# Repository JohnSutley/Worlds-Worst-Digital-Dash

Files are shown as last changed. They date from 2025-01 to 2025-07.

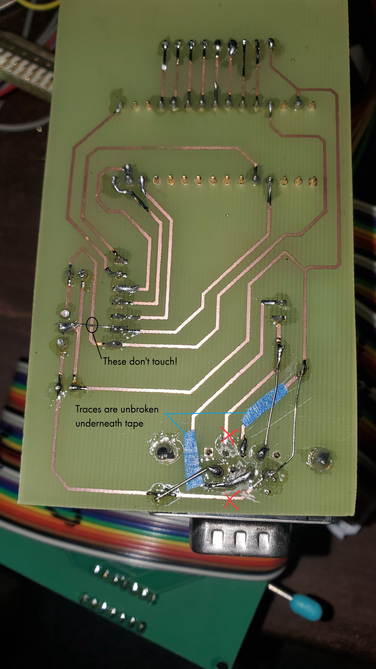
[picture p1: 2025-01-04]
PCBs/Version 1/Arduino attachment/Arduino Canbus Card/Project Note.jpg

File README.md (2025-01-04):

This folder contains the project files for the Worlds Worst Digital Dash
(Gameboy Digital Dash) project. If attempting to recreate version 1 of the
Arduino CANBUS card, please make a note of the included "Project Note" and 
"Project Note 2" pictures in the "Arduino Canbus Card" project folder, since 
I totally messed up the DB9 connector pinout and missed a trace leading to 
the 7805 voltage regulator. Also, I had to bridge some connections on top of 
the Arduino. Gotta admit, not my best work. The "reader.gb" file in the 
Gameboy Code folder is the pre-compiled binary that gets flashed to the EEPROM. 
The software used in this project is as follows:

-Kicad 7.0

-Autodesk Fusion 2.0.20494 x86_64

-Arduino IDE Version: 2.3.4

-GBDK-2020

-Savvy CAN V208

-Xgpro v12.66

-UltiMaker Cura 5.6.0

-LightBurn 1.6.03

-GIMP 2.10.36

-Visual Studio Code Version: 1.96.2

I think LightBurn was the only paid software I used, and that was for the
laser engraver.

Feel free to contact me with any questions regarding this project at
jcsutley@gmail.com. 

John Sutley - 2025

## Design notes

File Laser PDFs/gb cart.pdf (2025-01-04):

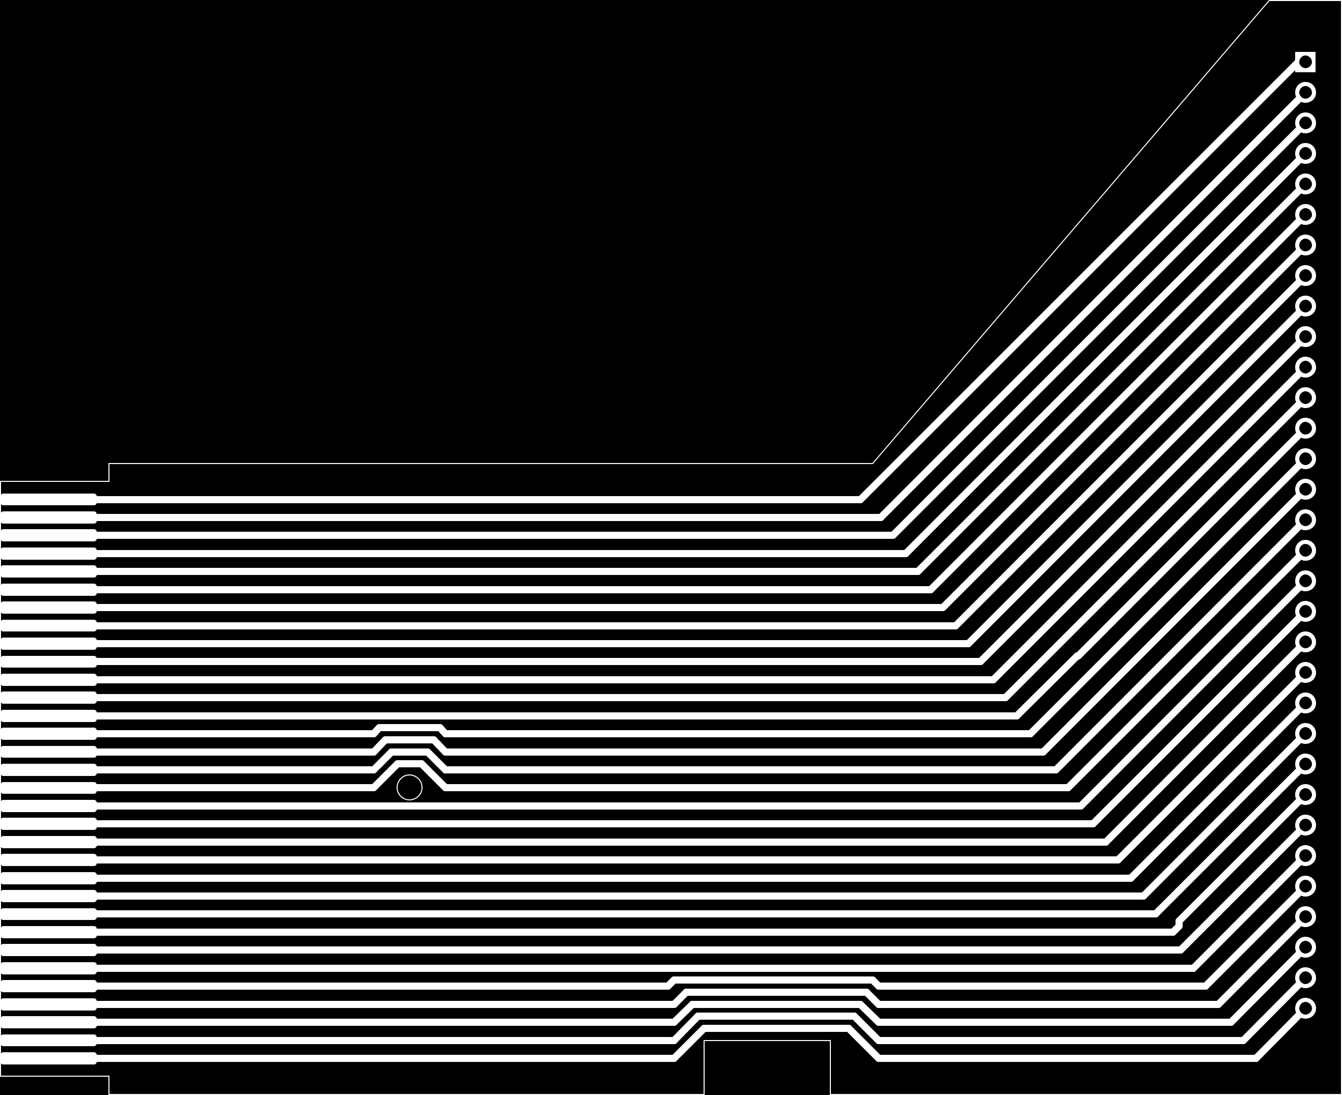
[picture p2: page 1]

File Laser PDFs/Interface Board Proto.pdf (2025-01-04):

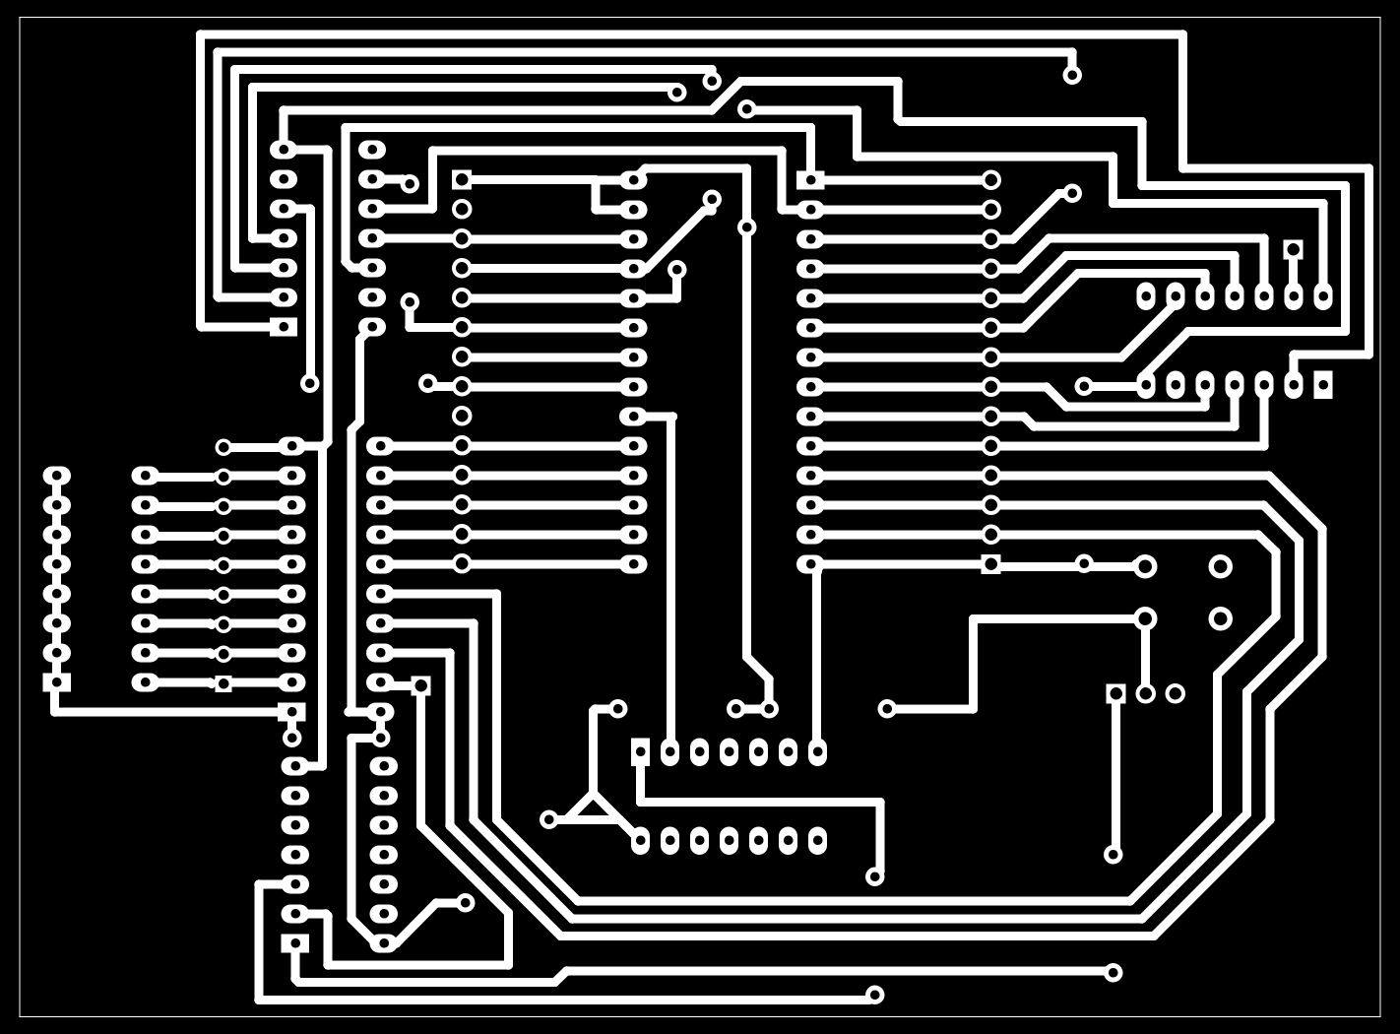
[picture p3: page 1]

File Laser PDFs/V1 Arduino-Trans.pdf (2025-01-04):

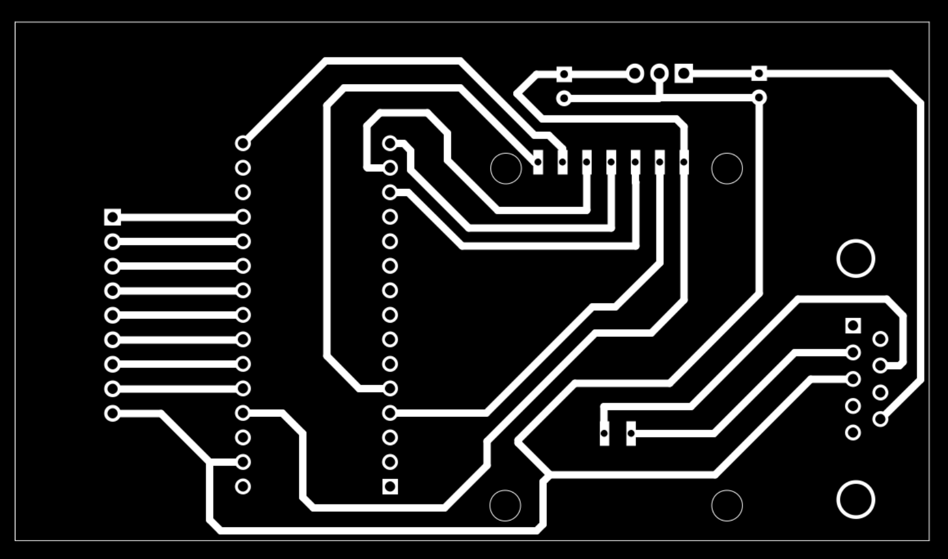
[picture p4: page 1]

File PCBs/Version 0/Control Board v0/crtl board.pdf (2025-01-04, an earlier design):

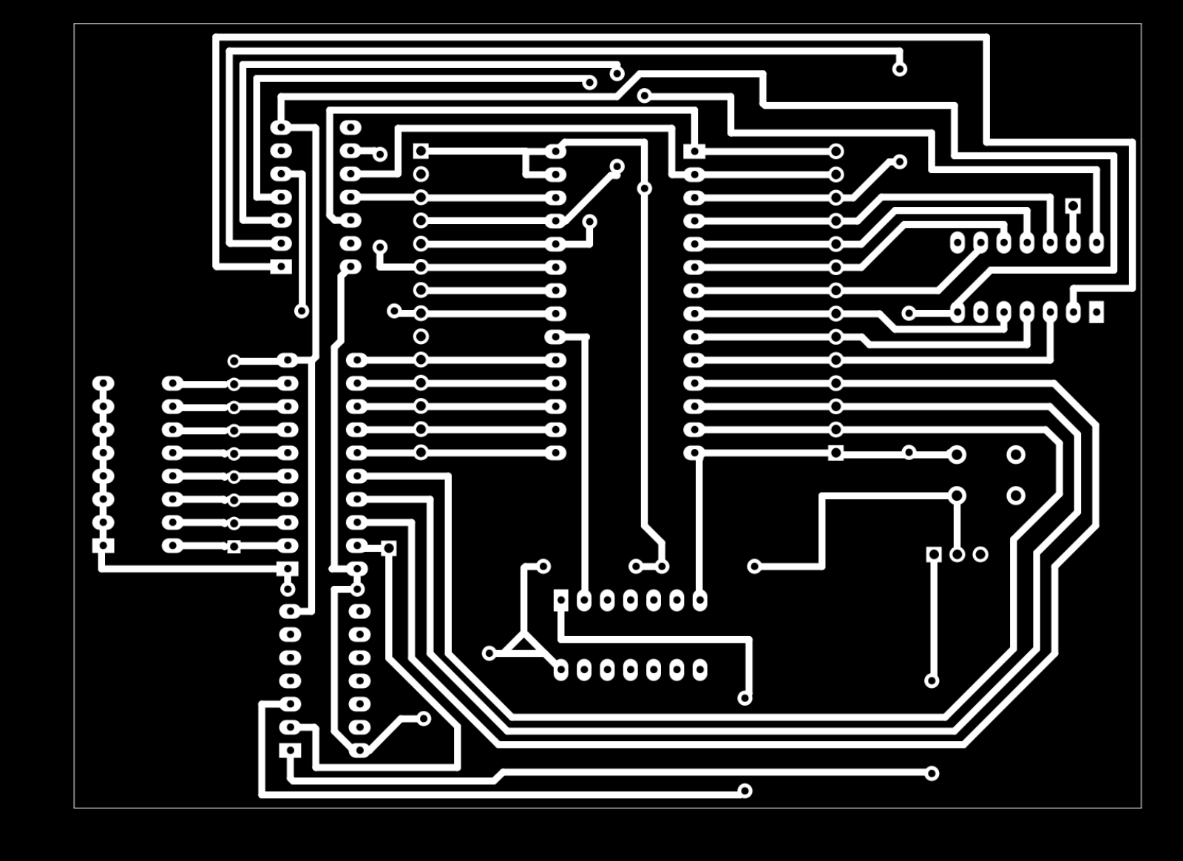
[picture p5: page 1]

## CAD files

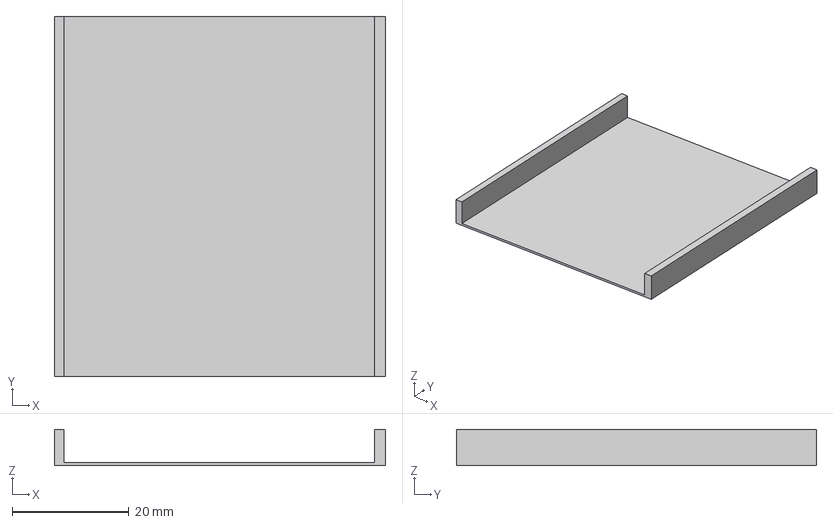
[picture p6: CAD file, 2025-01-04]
GB PAK Adapter/game boy pak shell v3.3mf
56.8 x 61.7 x 6.20 mm

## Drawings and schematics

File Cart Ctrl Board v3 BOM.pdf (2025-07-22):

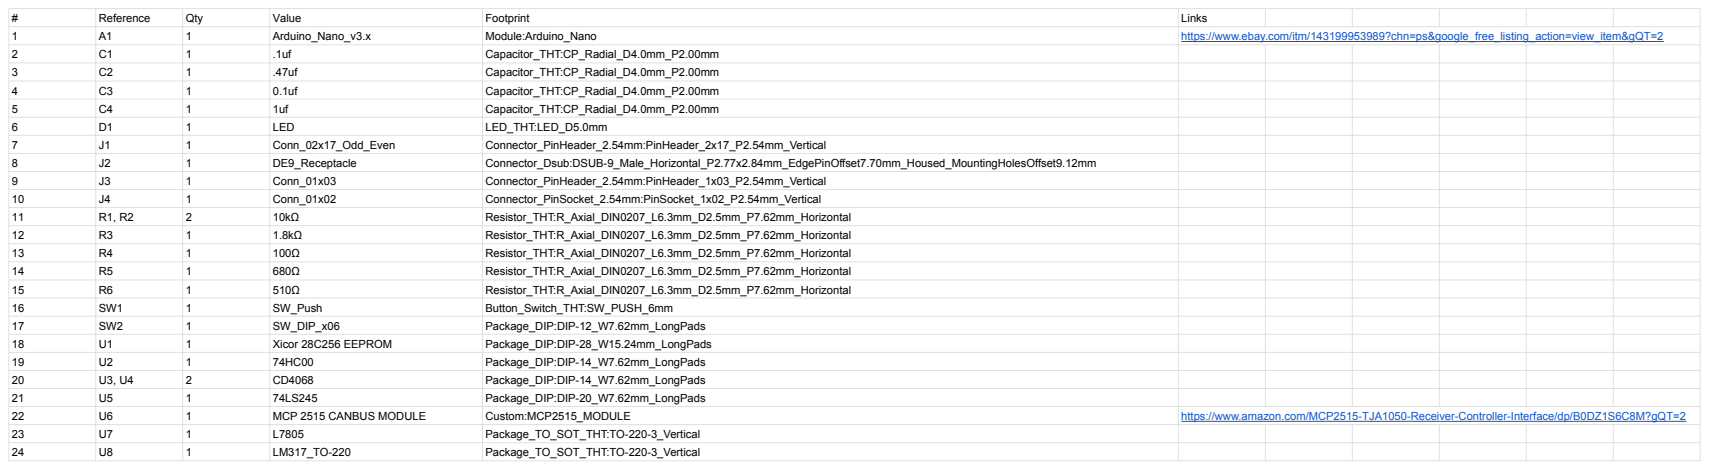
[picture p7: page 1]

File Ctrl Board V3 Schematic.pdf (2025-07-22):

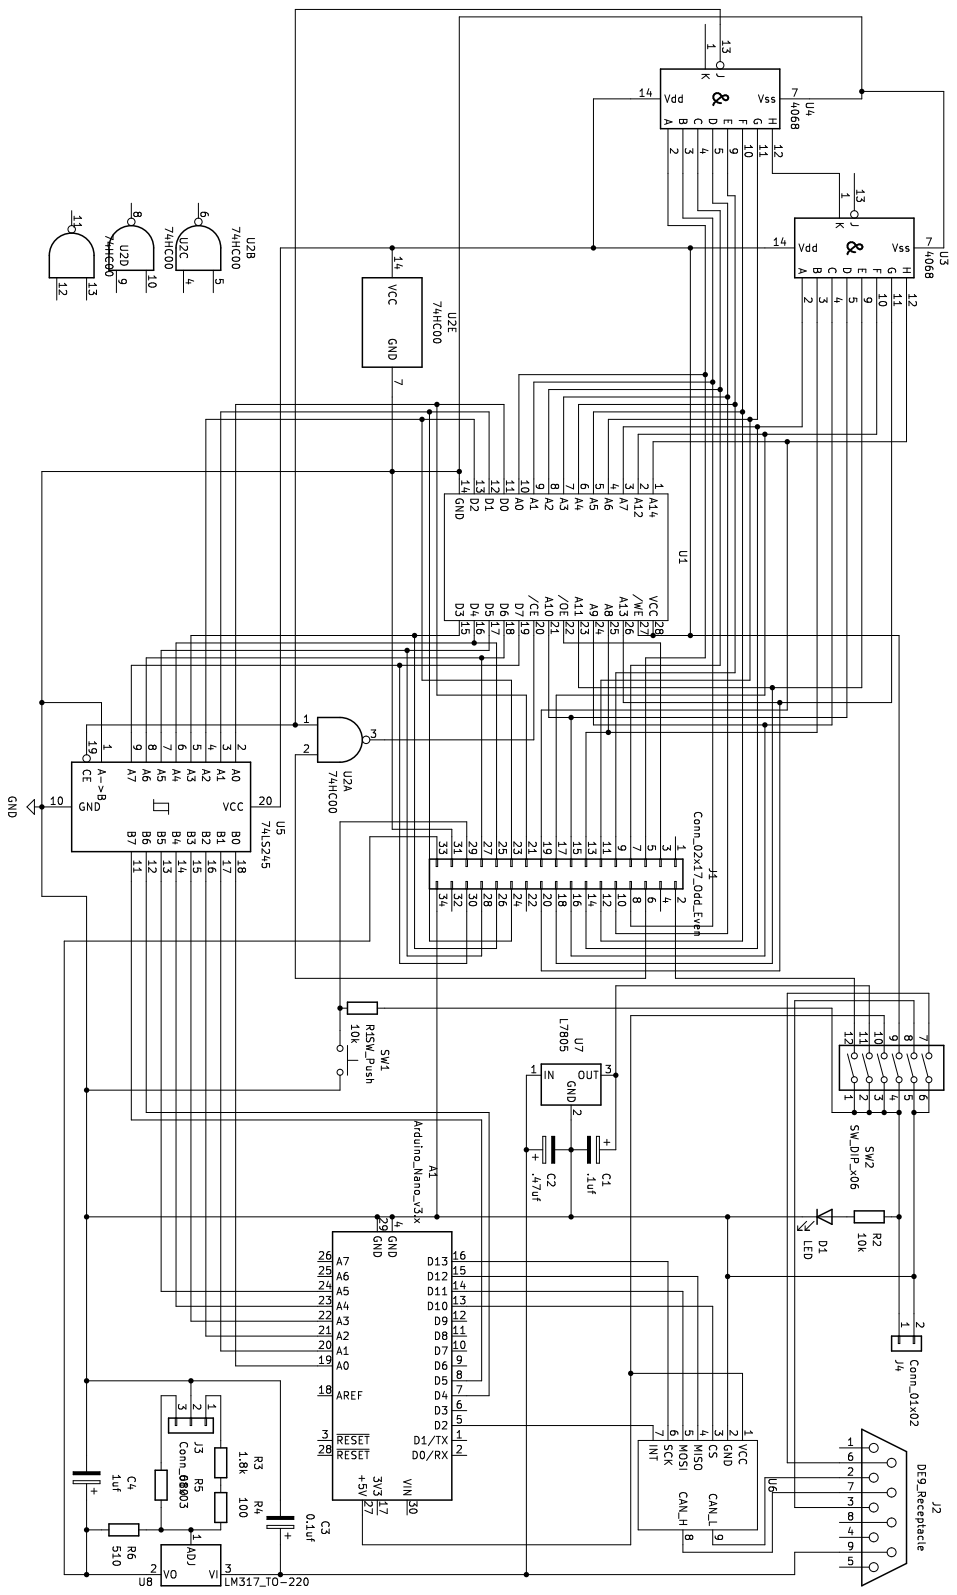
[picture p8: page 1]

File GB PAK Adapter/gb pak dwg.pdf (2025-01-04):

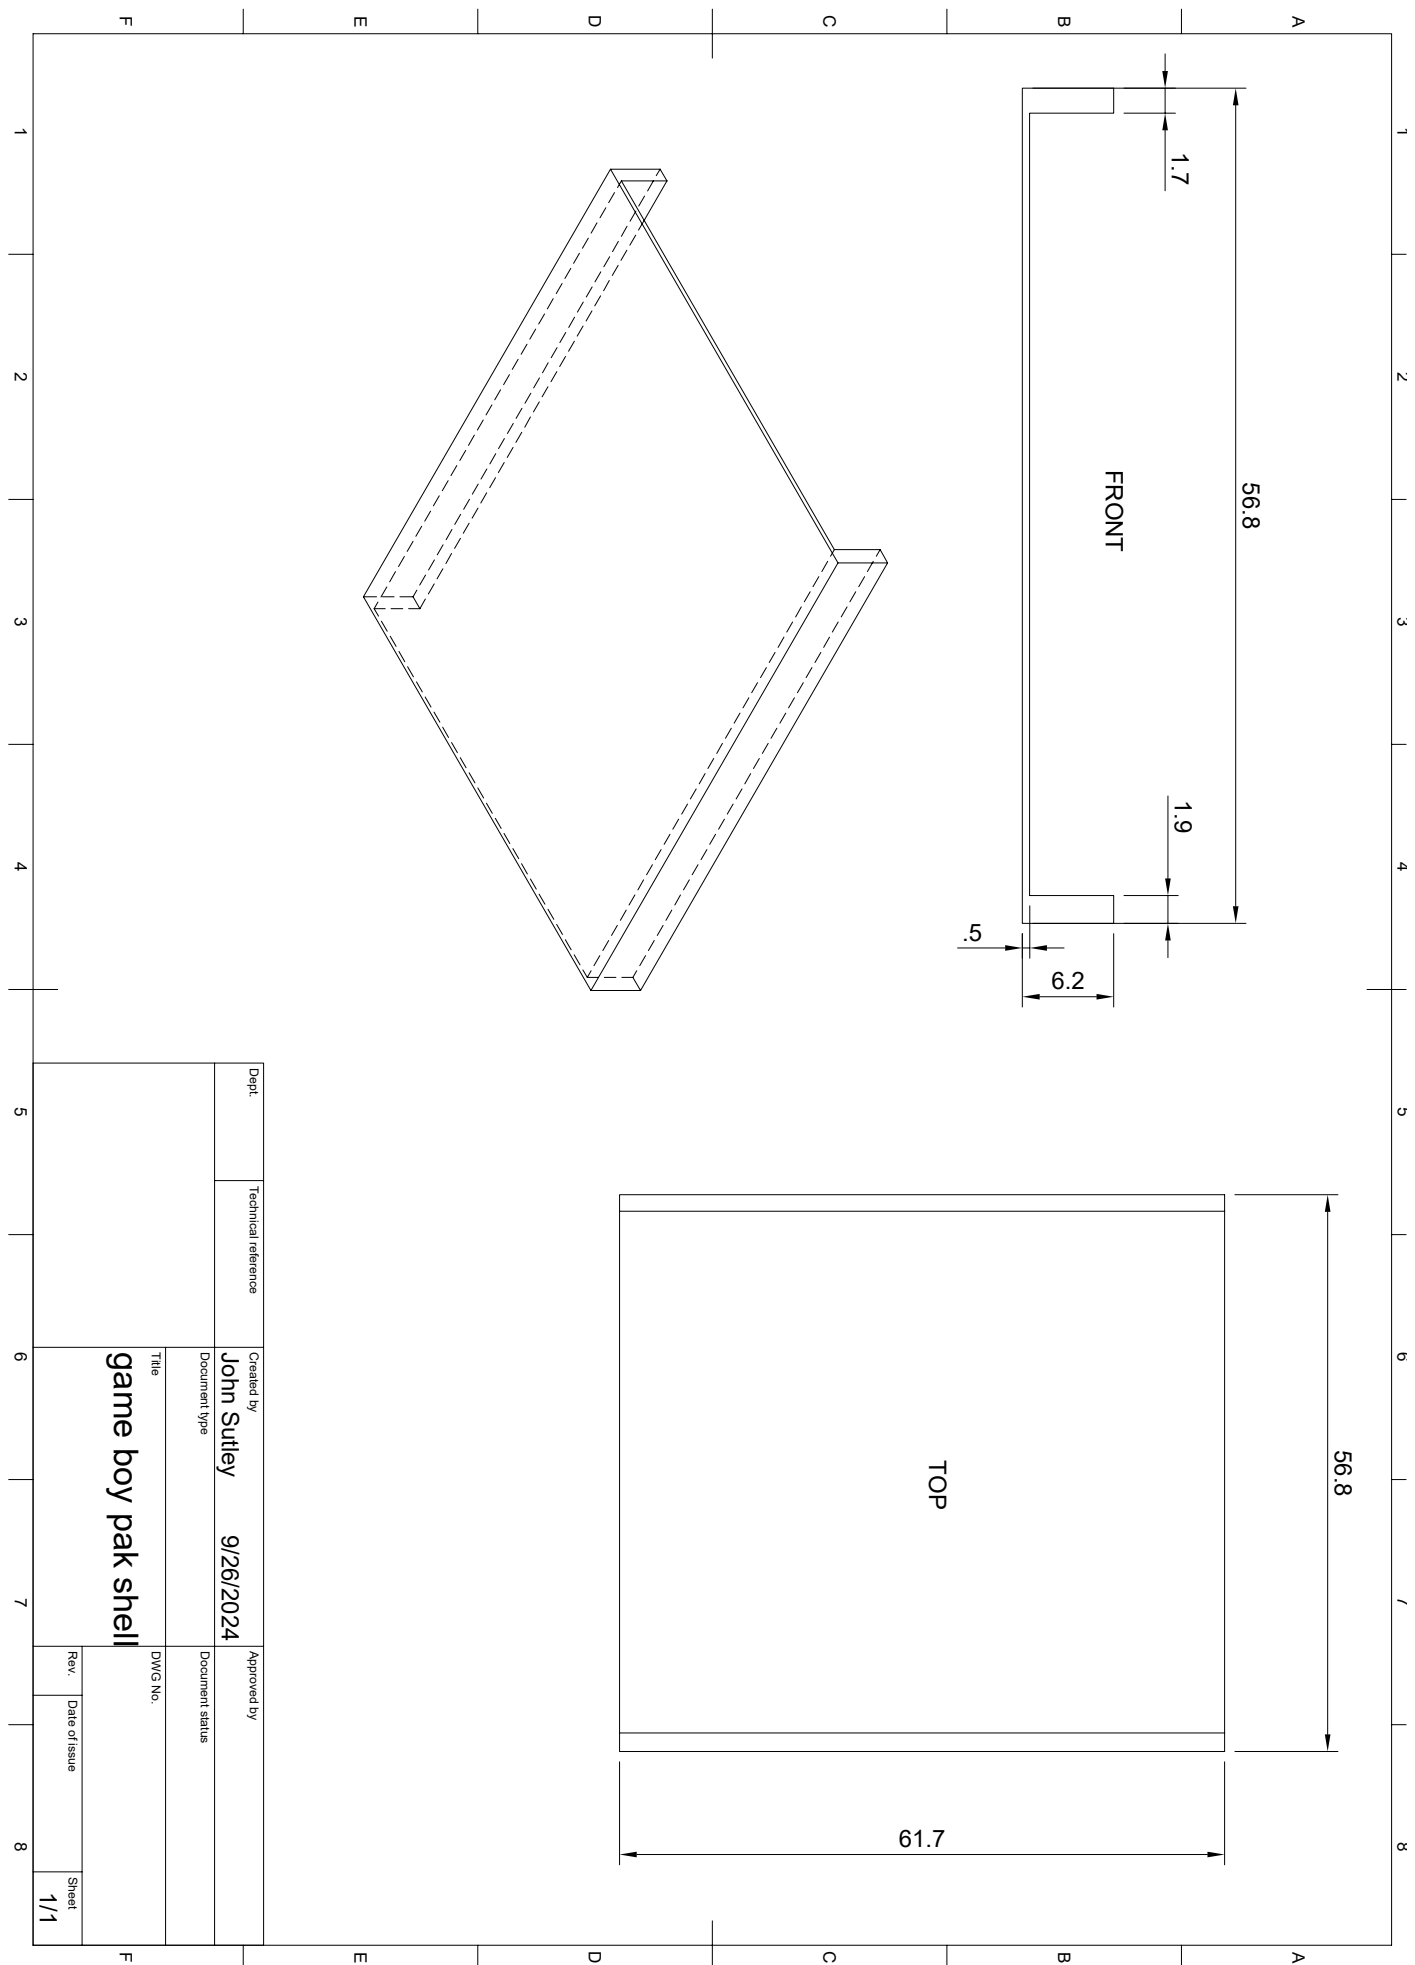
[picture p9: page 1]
61.7 FRONT TOP

1 A 2 3 4 5 6 7 8 1 2 3 4 5 6 7 8 FEDCB FEDCBA Dept. Technical reference Created by Approved by Title DWG No. Document type Document status Rev. Date of issue Sheet 9/26/2024 1/1 game boy pak shell John Sutley 1.7 1.9 56.8

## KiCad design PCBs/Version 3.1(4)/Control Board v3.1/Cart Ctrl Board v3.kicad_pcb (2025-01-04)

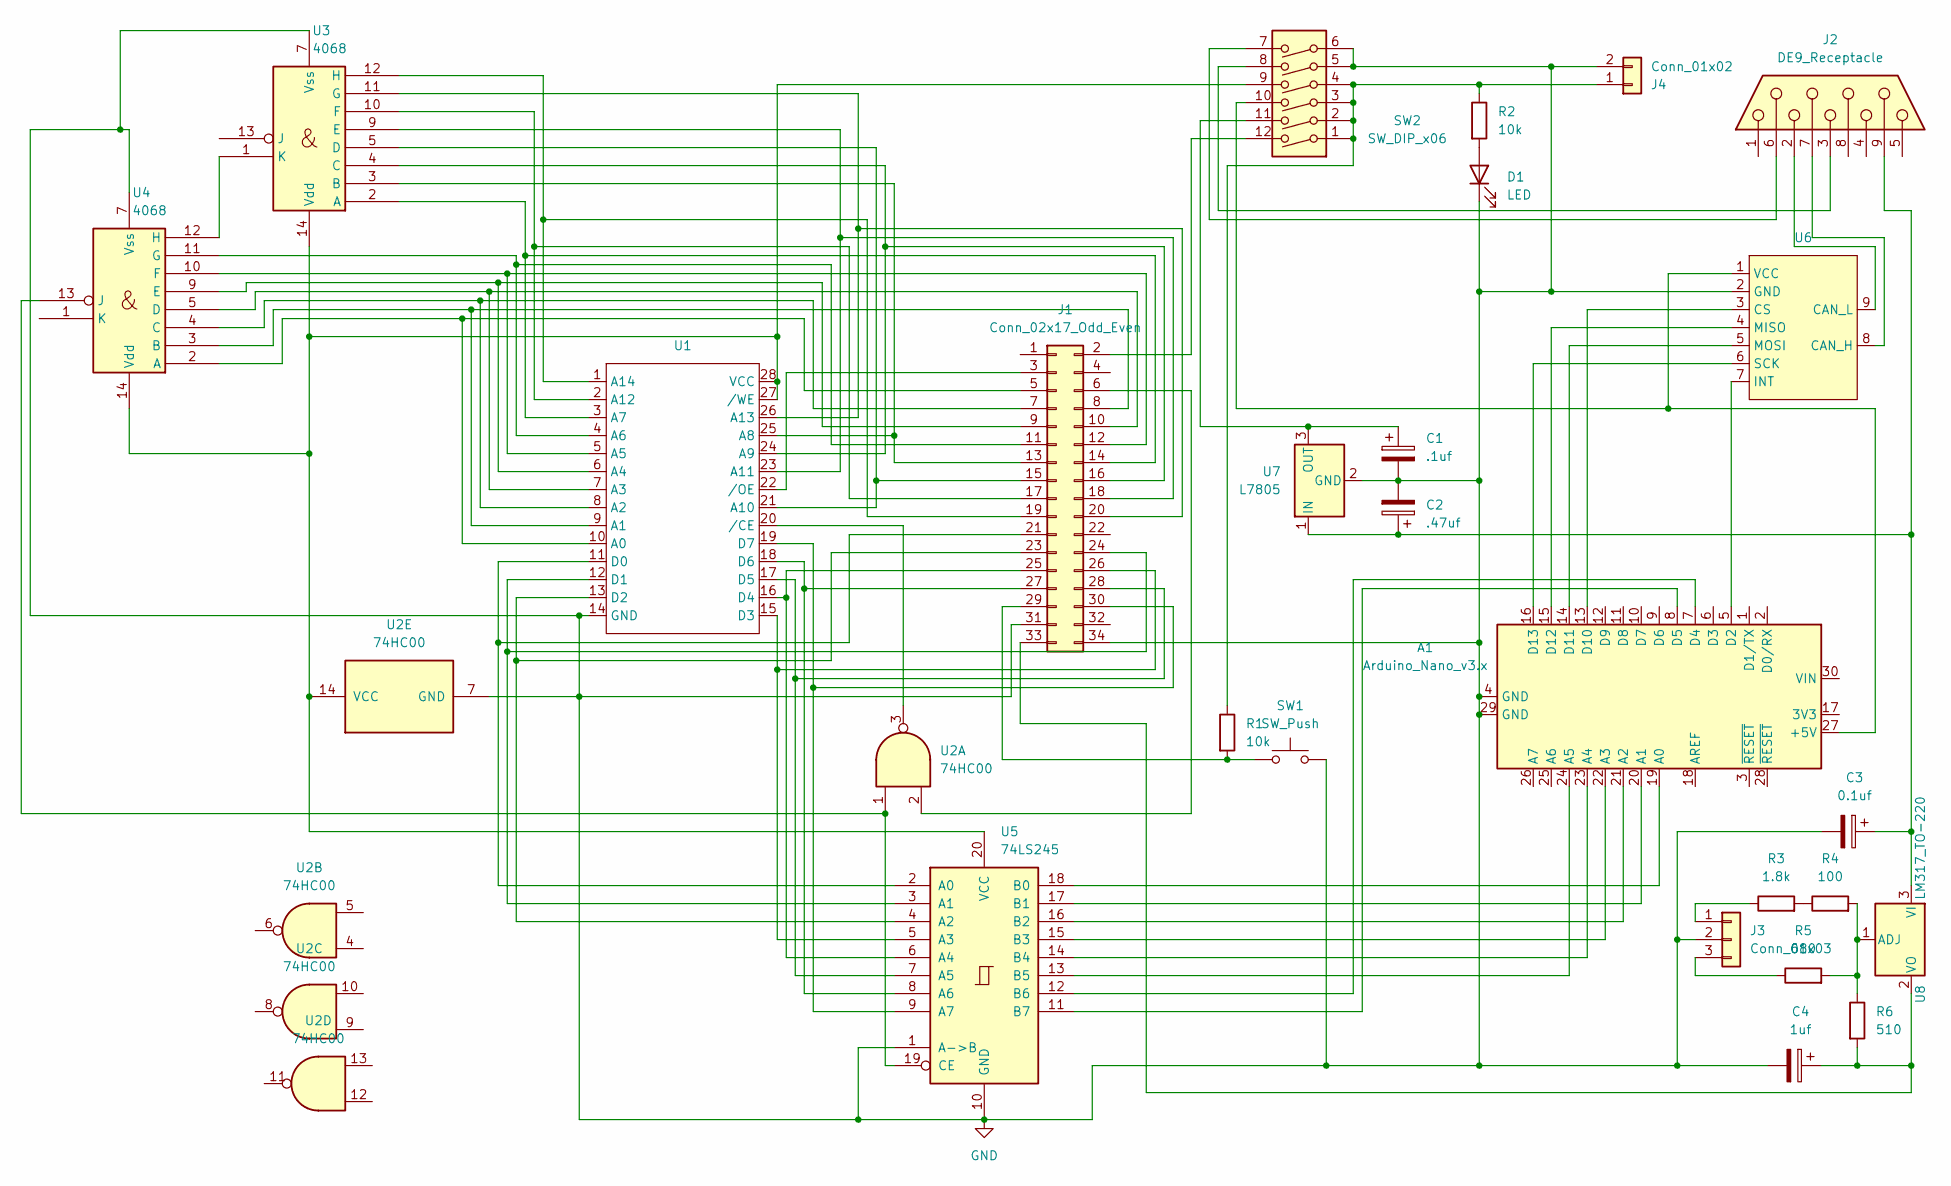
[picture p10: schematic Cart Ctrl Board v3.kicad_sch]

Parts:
A1: Arduino_Nano_v3.x; Arduino_Nano
C1: .1uf; CP_Radial_D4.0mm_P2.00mm
C2: .47uf; CP_Radial_D4.0mm_P2.00mm
C3: 0.1uf; CP_Radial_D4.0mm_P2.00mm
C4: 1uf; CP_Radial_D4.0mm_P2.00mm
D1: LED; LED_D5.0mm
J1: Conn_02x17_Odd_Even; PinHeader_2x17_P2.54mm_Vertical
J2: DE9_Receptacle; DSUB-9_Male_Horizontal_P2.77x2.84mm_EdgePinOffset7.70mm_Hou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
J3: Conn_01x03; PinHeader_1x03_P2.54mm_Vertical
J4: Conn_01x02; PinSocket_1x02_P2.54mm_Vertical
R1, R2: 10k; R_Axial_DIN0207_L6.3mm_D2.5mm_P7.62mm_Horizontal
R3: 1.8k; R_Axial_DIN0207_L6.3mm_D2.5mm_P7.62mm_Horizontal
R4: 100; R_Axial_DIN0207_L6.3mm_D2.5mm_P7.62mm_Horizontal
R5: 680; R_Axial_DIN0207_L6.3mm_D2.5mm_P7.62mm_Horizontal
R6: 510; R_Axial_DIN0207_L6.3mm_D2.5mm_P7.62mm_Horizontal
SW1: SW_Push; SW_PUSH_6mm
SW2: SW_DIP_x06; DIP-12_W7.62mm_LongPads
U1: DIP-28_W15.24mm_LongPads
U2: 74HC00; DIP-14_W7.62mm_LongPads
U3, U4: 4068; DIP-14_W7.62mm_LongPads
U5: 74LS245; DIP-20_W7.62mm_LongPads
U6: MCP2515_MODULE
U7: L7805; TO-220-3_Vertical
U8: LM317_TO-220; TO-220-3_Vertical

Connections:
GND: A1.4 (GND), A1.29 (GND), C1.2, C2.2, C3.2, C4.2, D1.1 (K), J1.31, J1.34, J3.2, J4.2, SW1.2, SW2.5, SW2.6, U1.14 (GND), U2.7 (GND), U3.7 (Vss), U4.7 (Vss), U5.1 (A->B), U5.10 (GND), U6.2 (GND), U7.2 (GND)
unnamed: A1.27 (+5V), SW2.10, U6.1 (VCC)
unnamed: A1.19 (A0), U5.18 (B0)
unnamed: A1.20 (A1), U5.17 (B1)
unnamed: A1.21 (A2), U5.16 (B2)
unnamed: A1.22 (A3), U5.15 (B3)
unnamed: A1.23 (A4), U5.14 (B4)
unnamed: A1.24 (A5), U5.13 (B5)
unnamed: A1.5 (D2), U6.7 (INT)
unnamed: A1.7 (D4), U5.12 (B6)
unnamed: A1.8 (D5), U5.11 (B7)
unnamed: A1.13 (D10), U6.3 (CS)
unnamed: A1.14 (D11), U6.5 (MOSI)
unnamed: A1.15 (D12), U6.4 (MISO)
unnamed: A1.16 (D13), U6.6 (SCK)
unnamed: D1.2 (A), R2.2
unnamed: J1.2, SW2.12
unnamed: J1.3, U1.22 (/OE)
unnamed: J1.5, U1.10 (A0), U4.2 (A)
unnamed: J1.6, U2.2
unnamed: J1.7, U1.8 (A2), U4.4 (C)
unnamed: J1.8, U1.9 (A1), U4.3 (B)
unnamed: J1.9, U1.6 (A4), U4.9 (E)
unnamed: J1.10, U1.7 (A3), U4.5 (D)
unnamed: J1.11, U1.4 (A6), U4.11 (G)
unnamed: J1.12, U1.5 (A5), U4.10 (F)
unnamed: J1.13, U1.25 (A8), U3.3 (B)
unnamed: J1.14, U1.3 (A7), U3.2 (A)
unnamed: J1.15, U1.21 (A10), U3.5 (D)
unnamed: J1.16, U1.24 (A9), U3.4 (C)
unnamed: J1.17, U1.2 (A12), U3.10 (F)
unnamed: J1.18, U1.23 (A11), U3.9 (E)
unnamed: J1.19, U1.1 (A14), U3.12 (H)
unnamed: J1.20, U1.26 (A13), U3.11 (G)
unnamed: J1.21, U1.11 (D0), U5.2 (A0)
unnamed: J1.23, U1.13 (D2), U5.4 (A2)
unnamed: J1.24, U1.12 (D1), U5.3 (A1)
unnamed: J1.25, U1.16 (D4), U5.6 (A4)
unnamed: J1.26, U1.15 (D3), U5.5 (A3)
unnamed: J1.27, U1.18 (D6), U5.8 (A6)
unnamed: J1.28, U1.17 (D5), U5.7 (A5)
unnamed: J1.29, R1.2, SW1.1
unnamed: J1.30, U1.19 (D7), U5.9 (A7)
unnamed: C4.1, J1.33, R6.2, U8.2 (VO)
unnamed: J2.3, SW2.8
unnamed: J2.6, SW2.7
unnamed: J3.1, R3.1
unnamed: J3.3, R5.1
unnamed: J4.1, R1.1, R2.1, SW2.1, SW2.2, SW2.3, SW2.4
unnamed: R3.2, R4.1
unnamed: SW2.9, U1.27 (/WE), U1.28 (VCC), U2.14 (VCC), U3.14 (Vdd), U4.14 (Vdd), U5.20 (VCC)
unnamed: U1.20 (/CE), U2.3
unnamed: U3.1 (K), U4.12 (H)
unnamed: U2.1, U4.13 (J), U5.19 (CE)
unnamed: J2.7, U6.8 (CAN_H)
unnamed: J2.2, U6.9 (CAN_L)
unnamed: C2.1, C3.1, J2.9, U7.1 (IN), U8.3 (VI)
unnamed: C1.1, SW2.11, U7.3 (OUT)
unnamed: R4.2, R5.2, R6.1, U8.1 (ADJ)

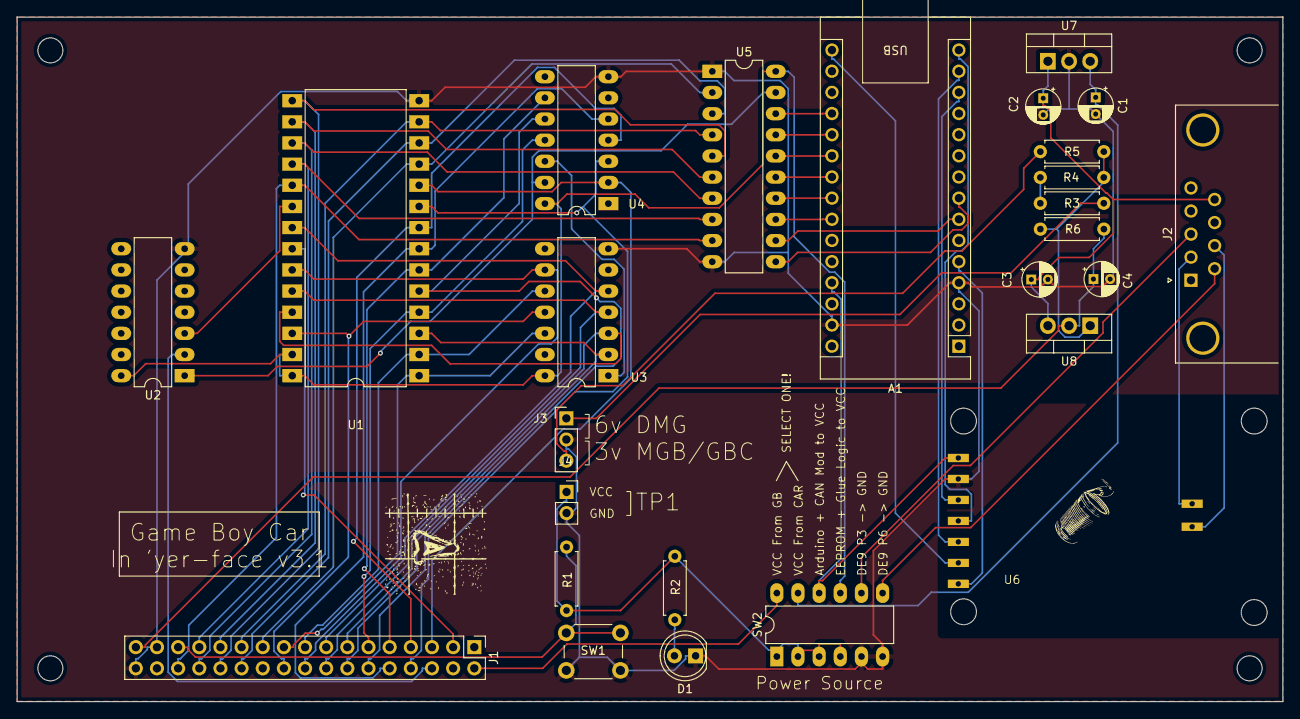
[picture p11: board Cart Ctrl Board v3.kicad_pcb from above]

Board: 2 copper layers, 152.0 x 82.2 mm, 26 parts (0 on the bottom side), 59 nets.

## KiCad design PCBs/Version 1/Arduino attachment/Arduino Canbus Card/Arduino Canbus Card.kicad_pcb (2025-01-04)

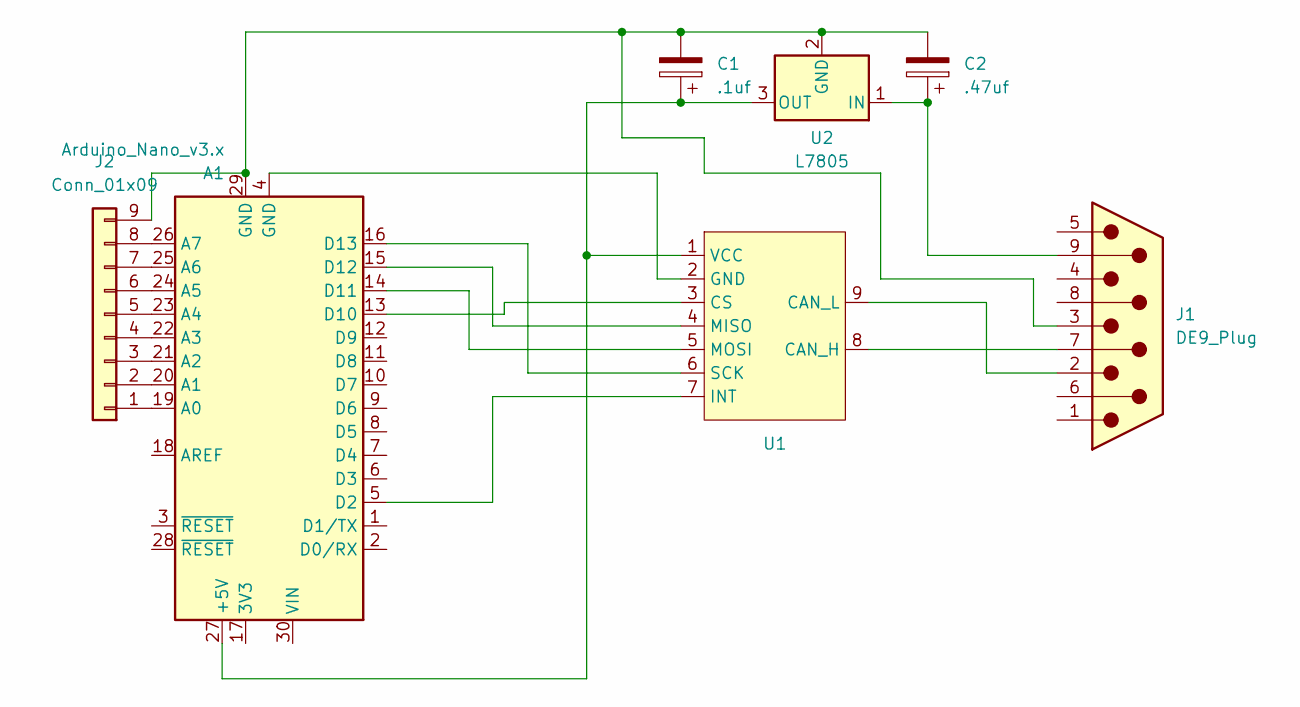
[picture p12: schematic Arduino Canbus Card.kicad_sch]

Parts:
A1: Arduino_Nano_v3.x; Arduino_Nano
C1: .1uf; CP_Radial_D5.0mm_P2.50mm
C2: .47uf; CP_Radial_D5.0mm_P2.50mm
J1: DE9_Plug; DSUB-9_Female_Horizontal_P2.77x2.84mm_EdgePinOffset4.94mm_H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
J2: Conn_01x09; PinSocket_1x09_P2.54mm_Horizontal
U1: MCP2515_MODULE
U2: L7805; TO-220-3_Vertical

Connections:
unnamed: A1.27 (+5V), C1.1, U1.1 (VCC), U2.3 (OUT)
unnamed: A1.19 (A0), J2.1
unnamed: A1.20 (A1), J2.2
unnamed: A1.21 (A2), J2.3
unnamed: A1.22 (A3), J2.4
unnamed: A1.23 (A4), J2.5
unnamed: A1.24 (A5), J2.6
unnamed: A1.25 (A6), J2.7
unnamed: A1.26 (A7), J2.8
unnamed: A1.5 (D2), U1.7 (INT)
unnamed: A1.13 (D10), U1.3 (CS)
unnamed: A1.14 (D11), U1.5 (MOSI)
unnamed: A1.15 (D12), U1.4 (MISO)
unnamed: A1.16 (D13), U1.6 (SCK)
unnamed: A1.29 (GND), C1.2, C2.2, J1.3, J2.9, U2.2 (GND)
unnamed: J1.7, U1.8 (CAN_H)
unnamed: J1.2, U1.9 (CAN_L)
unnamed: A1.4 (GND), U1.2 (GND)
unnamed: C2.1, J1.9, U2.1 (IN)

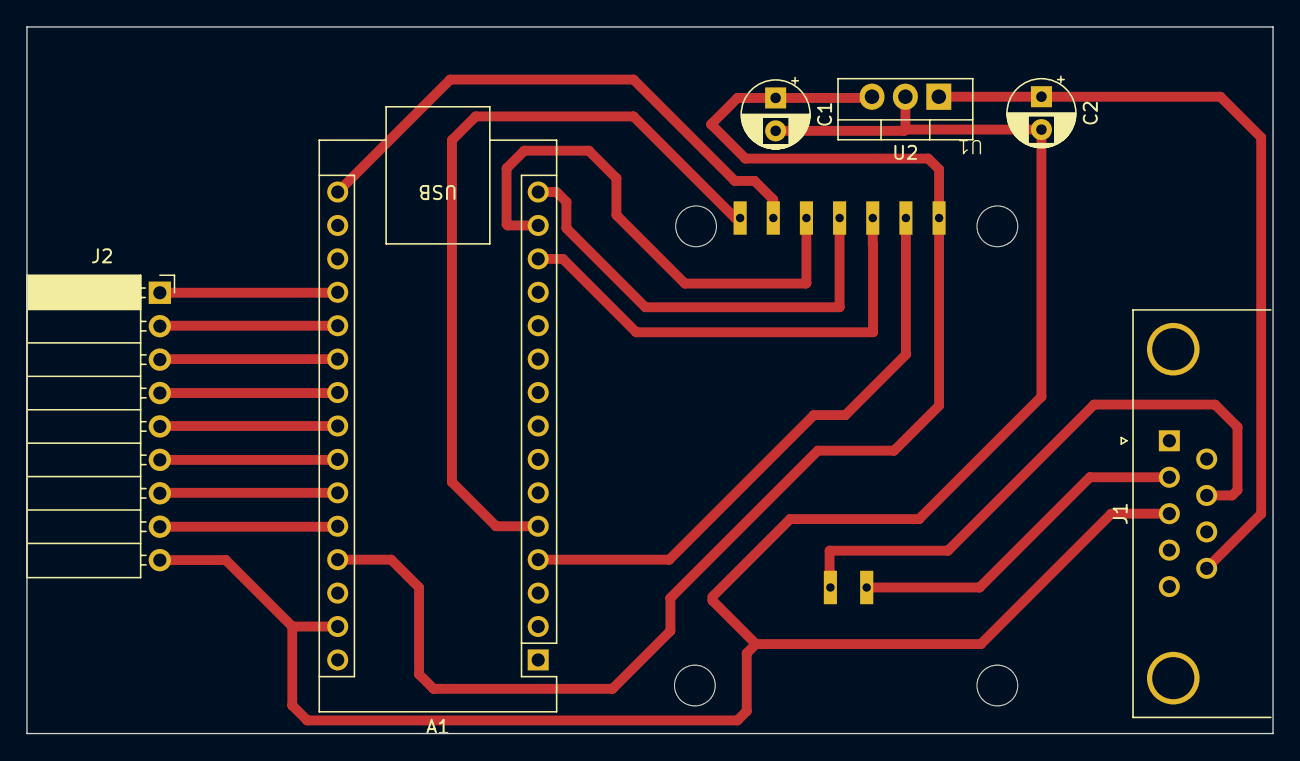
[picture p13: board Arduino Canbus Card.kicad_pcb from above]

Board: 2 copper layers, 94.7 x 53.7 mm, 7 parts (0 on the bottom side), 19 nets.

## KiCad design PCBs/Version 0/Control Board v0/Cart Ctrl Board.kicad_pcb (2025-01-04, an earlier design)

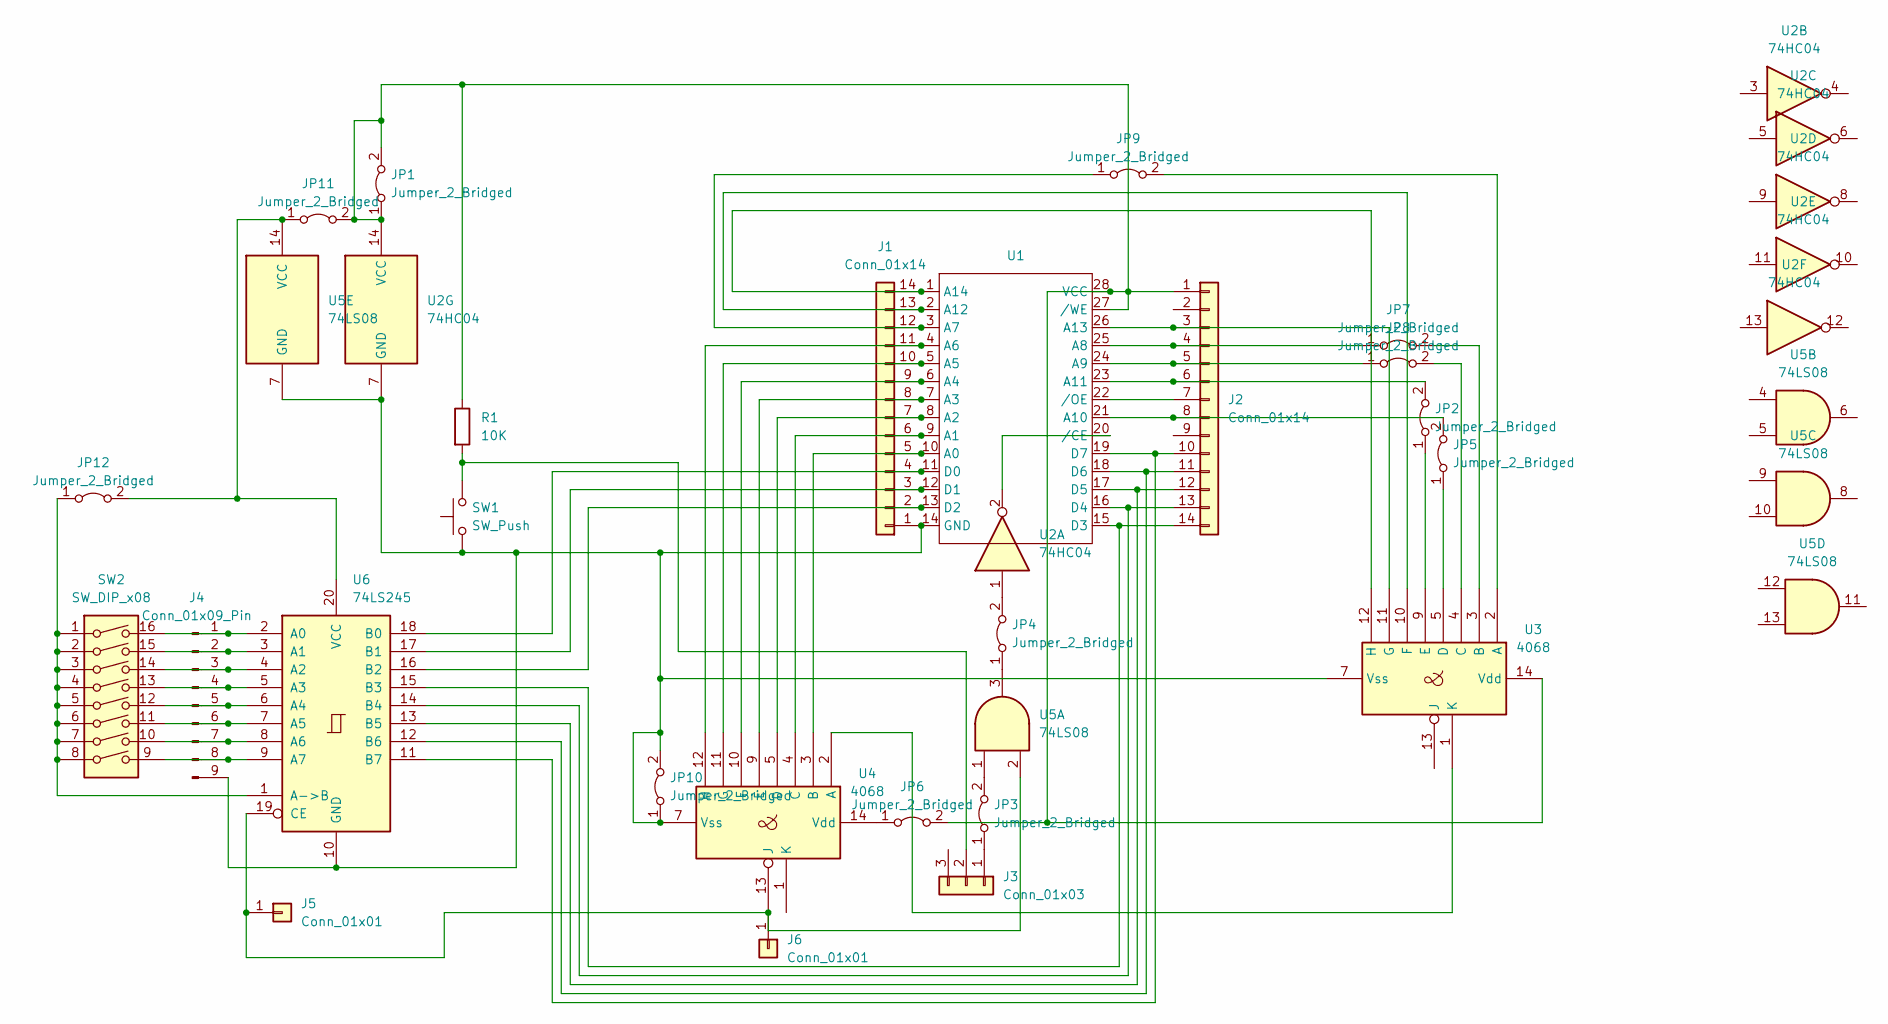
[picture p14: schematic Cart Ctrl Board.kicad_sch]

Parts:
J1, J2: Conn_01x14; PinHeader_1x14_P2.54mm_Vertical
J3: Conn_01x03; PinHeader_1x03_P2.54mm_Vertical
J4: Conn_01x09_Pin; SIP-9_22.3x3mm_P2.54mm
J5, J6: Conn_01x01; PinHeader_1x01_P2.54mm_Vertical
JP1, JP2, JP3, JP4, JP5, JP6, JP7, JP9, JP11: Jumper_2_Bridged; R_Axial_DIN0207_L6.3mm_D2.5mm_P10.16mm_Horizontal
JP8, JP10: Jumper_2_Bridged; R_Axial_DIN0207_L6.3mm_D2.5mm_P15.24mm_Horizontal
JP12: Jumper_2_Bridged; R_Axial_DIN0207_L6.3mm_D2.5mm_P7.62mm_Horizontal
R1: 10K; R_Axial_DIN0207_L6.3mm_D2.5mm_P10.16mm_Horizontal
SW1: SW_Push; SW_PUSH_6mm_H5mm
SW2: SW_DIP_x08; DIP-16_W7.62mm_LongPads
U1: DIP-28_W15.24mm_LongPads
U2: 74HC04; DIP-14_W7.62mm_LongPads
U3, U4: 4068; DIP-14_W7.62mm_LongPads
U5: 74LS08; DIP-14_W7.62mm_LongPads
U6: 74LS245; DIP-20_W7.62mm_LongPads

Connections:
unnamed: J1.1, J4.9, JP10.1 (A), JP10.2 (B), SW1.1, U1.14 (GND), U2.7 (GND), U3.7 (Vss), U4.7 (Vss), U5.7 (GND), U6.10 (GND)
unnamed: J1.2, U1.13 (D2), U6.16 (B2)
unnamed: J1.3, U1.12 (D1), U6.17 (B1)
unnamed: J1.4, U1.11 (D0), U6.18 (B0)
unnamed: J1.5, U1.10 (A0), U4.3 (B)
unnamed: J1.6, U1.9 (A1), U4.4 (C)
unnamed: J1.7, U1.8 (A2), U4.5 (D)
unnamed: J1.8, U1.7 (A3), U4.9 (E)
unnamed: J1.9, U1.6 (A4), U4.10 (F)
unnamed: J1.10, U1.5 (A5), U4.11 (G)
unnamed: J1.11, U1.4 (A6), U4.12 (H)
unnamed: J1.12, JP9.1 (A), U1.3 (A7)
unnamed: J1.13, U1.2 (A12), U3.10 (F)
unnamed: J1.14, U1.1 (A14), U3.12 (H)
unnamed: J2.1, JP1.1 (A), JP1.2 (B), JP6.2 (B), JP11.2 (B), R1.1, U1.27 (/WE), U1.28 (VCC), U2.14 (VCC), U3.14 (Vdd)
unnamed: J2.3, U1.26 (A13), U3.11 (G)
unnamed: J2.4, JP7.1 (A), U1.25 (A8)
unnamed: J2.5, JP8.1 (A), U1.24 (A9)
unnamed: J2.6, JP2.2 (B), U1.23 (A11)
unnamed: J2.7, U1.22 (/OE)
unnamed: J2.8, JP5.2 (B), U1.21 (A10)
unnamed: J2.10, U1.19 (D7), U6.11 (B7)
unnamed: J2.11, U1.18 (D6), U6.12 (B6)
unnamed: J2.12, U1.17 (D5), U6.13 (B5)
unnamed: J2.13, U1.16 (D4), U6.14 (B4)
unnamed: J2.14, U1.15 (D3), U6.15 (B3)
unnamed: J3.1, JP3.1 (A)
unnamed: J3.2, R1.2, SW1.2
unnamed: J4.1, SW2.16, U6.2 (A0)
unnamed: J4.2, SW2.15, U6.3 (A1)
unnamed: J4.3, SW2.14, U6.4 (A2)
unnamed: J4.4, SW2.13, U6.5 (A3)
unnamed: J4.5, SW2.12, U6.6 (A4)
unnamed: J4.6, SW2.11, U6.7 (A5)
unnamed: J4.7, SW2.10, U6.8 (A6)
unnamed: J4.8, SW2.9, U6.9 (A7)
unnamed: J5.1, J6.1, U4.13 (J), U5.2, U6.19 (CE)
unnamed: JP2.1 (A), U3.9 (E)
unnamed: JP3.2 (B), U5.1
unnamed: JP4.1 (A), U5.3
unnamed: JP4.2 (B), U2.1
unnamed: JP5.1 (A), U3.5 (D)
unnamed: JP6.1 (A), U4.14 (Vdd)
unnamed: JP7.2 (B), U3.3 (B)
unnamed: JP8.2 (B), U3.4 (C)
unnamed: JP9.2 (B), U3.2 (A)
unnamed: JP11.1 (A), JP12.2 (B), U5.14 (VCC), U6.20 (VCC)
unnamed: JP12.1 (A), SW2.1, SW2.2, SW2.3, SW2.4, SW2.5, SW2.6, SW2.7, SW2.8, U6.1 (A->B)
unnamed: U1.20 (/CE), U2.2
unnamed: U3.1 (K), U4.2 (A)

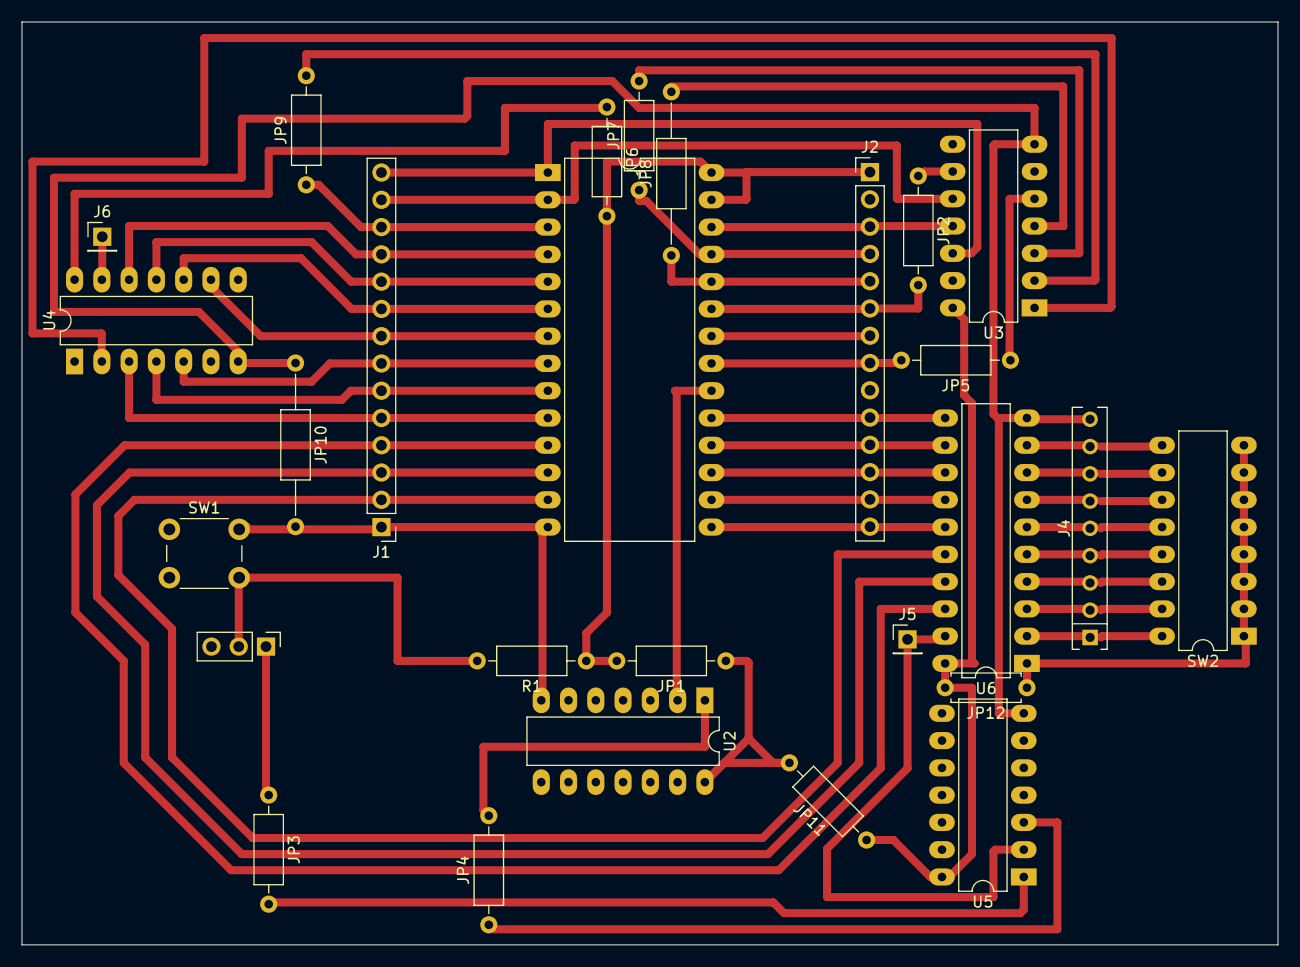
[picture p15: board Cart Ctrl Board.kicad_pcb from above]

Board: 2 copper layers, 117.0 x 85.9 mm, 27 parts (0 on the bottom side), 50 nets.

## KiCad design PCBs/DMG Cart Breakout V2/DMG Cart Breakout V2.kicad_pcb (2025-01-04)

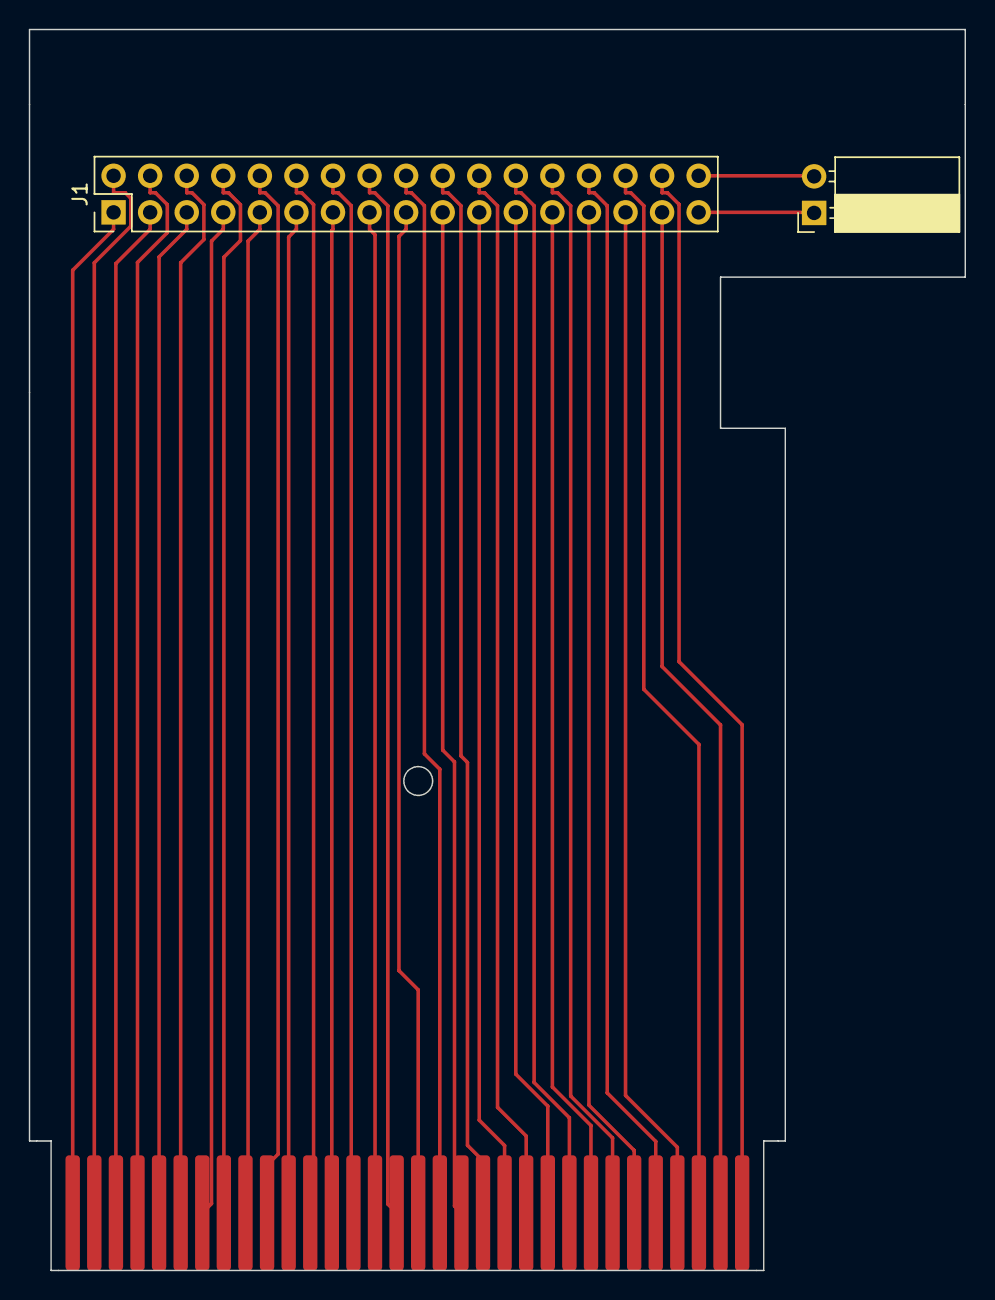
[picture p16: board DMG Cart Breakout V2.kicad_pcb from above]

Board: 2 copper layers, 65.0 x 86.2 mm, 3 parts (0 on the bottom side), 34 nets.

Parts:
CONN1: DMG_Cart
J1: Conn_02x17_Counter_Clockwise; PinHeader_2x17_P2.54mm_Vertical
PWR: Conn_01x02; PinSocket_1x02_P2.54mm_Horizontal

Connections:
GND: CONN1.32 (GND), J1.32
unnamed: CONN1.5 (!CS_RAM), J1.5
unnamed: CONN1.4 (!RD), J1.4
unnamed: CONN1.30 (!Reset), J1.30
unnamed: CONN1.3 (!WR), J1.3
unnamed: CONN1.1 (+5), J1.1
unnamed: CONN1.6 (A0), J1.6
unnamed: CONN1.7 (A1), J1.7
unnamed: CONN1.8 (A2), J1.8
unnamed: CONN1.9 (A3), J1.9
unnamed: CONN1.10 (A4), J1.10
unnamed: CONN1.11 (A5), J1.11
unnamed: CONN1.12 (A6), J1.12
unnamed: CONN1.13 (A7), J1.13
unnamed: CONN1.14 (A8), J1.14
unnamed: CONN1.15 (A9), J1.15
unnamed: CONN1.16 (A10), J1.16
unnamed: CONN1.17 (A11), J1.17
unnamed: CONN1.18 (A12), J1.18
unnamed: CONN1.19 (A13), J1.19
unnamed: CONN1.20 (A14), J1.20
unnamed: CONN1.21 (A15), J1.21
unnamed: CONN1.31 (Audio_In), J1.31
unnamed: CONN1.2 (CLK), J1.2
unnamed: CONN1.22 (D0), J1.22
unnamed: CONN1.23 (D1), J1.23
unnamed: CONN1.24 (D2), J1.24
unnamed: CONN1.25 (D3), J1.25
unnamed: CONN1.26 (D4), J1.26
unnamed: CONN1.27 (D5), J1.27
unnamed: CONN1.28 (D6), J1.28
unnamed: CONN1.29 (D7), J1.29
unnamed: J1.33, PWR.1
unnamed: J1.34, PWR.2

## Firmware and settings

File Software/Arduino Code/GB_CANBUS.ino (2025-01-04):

#include <SPI.h>
#include <mcp2515.h> //autowp MCP2515 Library

struct can_frame canMsg;
MCP2515 mcp2515(10); //CS Line on pin 10

void setup() 
{
  pinMode(14, OUTPUT);
  pinMode(15, OUTPUT);
  pinMode(16, OUTPUT);
  pinMode(17, OUTPUT);
  pinMode(18, OUTPUT);
  pinMode(19, OUTPUT);
  pinMode(4, OUTPUT);
  pinMode(5, OUTPUT);

  mcp2515.reset();
  mcp2515.setBitrate(CAN_500KBPS, MCP_8MHZ); // change to MCP_16MHZ for prototype board
  mcp2515.setNormalMode();
}

byte MPH = 0;

void bitPrinter()
{
  for (int i = 14; i < 20; i++)
    {
     digitalWrite(i, bitRead(MPH, i-14));
    }

  digitalWrite(4, bitRead(MPH, 6));
  digitalWrite(5, bitRead(MPH, 7));
}


void loop() 
{
  
  if (mcp2515.readMessage(&canMsg) == MCP2515::ERROR_OK && (canMsg.can_id == 0xa0)) 
    {
      MPH = 0.62*(canMsg.data[4]);
      bitPrinter();
    }

}
